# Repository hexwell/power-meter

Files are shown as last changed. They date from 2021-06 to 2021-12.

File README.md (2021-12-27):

# Power Meter

A power meter to read the energy consumption of my house and sound an alert in case it exeeds a threshold.
It consist of two devices:
- A meter that measures the power value and broadcasts it
- An alarm that receives the value and upon need sounds the alarm

Current sensing is done via an external current transformer (CT).

## Meter pictures

TODO

## Firmware

The firmware of both devices can be flashed with the Arduino IDE software, selecting the **Arduino Leonardo** board.

### Libraries

- [RF24](https://github.com/nRF24/RF24)
- [LiquidCrystal_I2C](https://github.com/johnrickman/LiquidCrystal_I2C)

## Early prototype

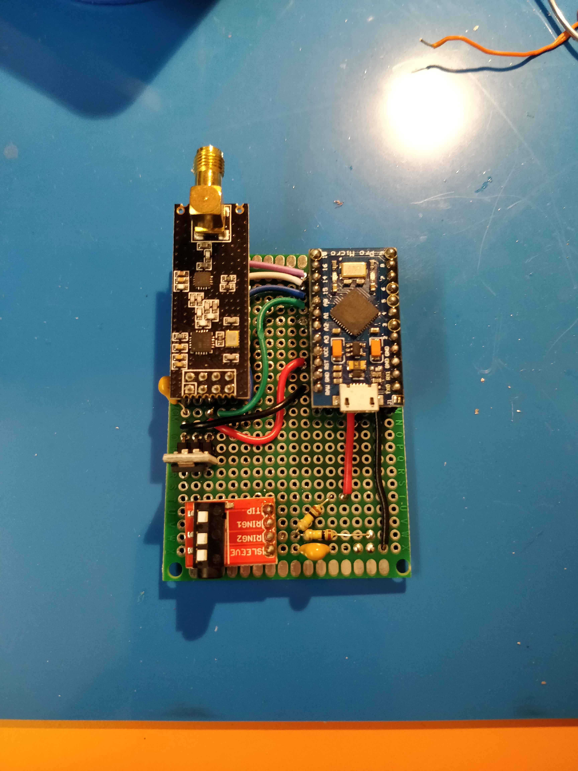
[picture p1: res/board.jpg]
board

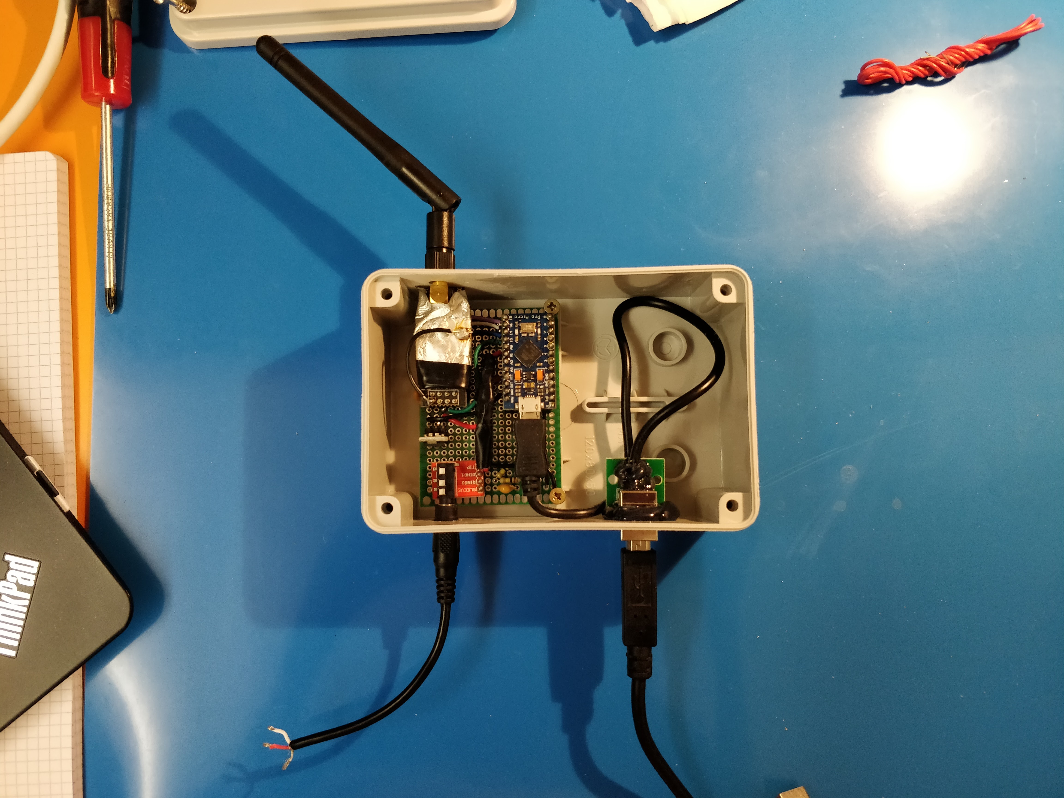
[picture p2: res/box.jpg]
box


## Notes

- A _true_ RMS reading of the sensor is crucial in order to get the real power value. The RMS reading is because of the nature of AC currents. The _true_ RMS is necessary because of the different current waveform of various types of loads (resistive, inductive, capacitive, etc.)
- Power consumption of the final build is .05 A at 5 V
- If the board ever gets **bricked**, [my guide](https://github.com/hexwell/notes-public/blob/master/en/electronics/pro_micro_brick.md) might be of use.
- OpenMeter update rate: 2s
- It might be nice to keep in this readme some pictures from the prototype when I design the PCB and update it.

## Theoretical resolution limits of SCT-013-000V current transformer (CT)

                    // Mains Characteristics
                    rms grid voltage = 230

                    transformer input = 100 A
                   transformer output = 1 V

                                  vcc = 4.683 V
                        adc divisions = 1024

                   volts per division = vcc / adc divisions
                                      = 0.004573
      divisions per transformer_range = transformer output / volts per division
                                      = 218
                    amps per division = transformer input / divisions per transformer_range
                                      = 0.4587
                           resolution = amps per division * rms_grid_voltage
                                      = 105.5010 W

    A lower rating transformer version can be used to get better resolution.
    This circuit can only take (VBUS / 2) input voltage, so the maximum peak current the meter
    can take is "transformer input current" * (VBUS / 2) / "transformer output voltage".
    For electrical systems rated 3.3 kW at 230 V the maximum amperage is 14.34 A,
    but peaks can greatly exceed this value, so at least 10x of this value should be accounted for in the design and transformer choice.
    The 60 A version is pretty much as low as it's possible to go.

## Questioning the whole thing

Since measuring power using just a current transformer is probably not really accurate, another option is reading the power measurement of the energy company's power meter directly, via it's IR port. That would require a lot of work tho, since the protocol needs to be reverse engineered. Irony of sorts, my italian energy company's meter is named OpenMeter.

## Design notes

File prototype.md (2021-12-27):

## Prototype circuit design notes

The circuit of both devices is pretty trivial. For both devices it's just an Arduino Pro Micro with an NRF24L01 transceiver (connected via the standard SPI configuration) and voltage regulation since the Arduino I had laying around was a 5V version and the transceiver is 3.3V. In addition to this, the meter has a voltage divider to DC bias the sensor and the alarm has a speaker directly connected between GND and a pin. Below are some considerations on actually assembling the devices:

- An SCT-013-000V current transformer with integrated burden resistor is used, because I didn't have a precise enough one. The other model (SCT-013-000) tho had integrated TVS diodes for protection instead, that now I need to integrate externally. (See note)
- A voltage divider DC-biases the current transformer/sensor in order to move the current waveform in the safe and measurable range of the Arduino ADC (as in the negative half cycle the voltage across the sensor is negative). The capacitor to ground is for stability of the bias voltage
- A 10 μF capacitor is placed between the power rails of the Arduino, as close as possible to it, for ADC stability as it need a stable supply to make precise measurements
- A shielded cable is used to carry the signal from the the sensor to the Arduino, although it probably is not needed as the frequency is only 50 Hz
- A NRF24L01+PA+LNA transceiver module (with RFAXIS RFX2401C chip) is used. The version with the RFAXIS PA+LNA was chosen for better range and for the SMA connector, allowing for an external (outside of project enclosure) and orientable antenna
- A 3.3 V regulator module with some capacitors on board off of Amazon is used to supply the transceiver. It saves space and does the job fine
- An additional 10 μF stability/noise filtering capacitor is placed between the transceiver power rails, as close as possible to it, just to be sure (not required with the regulator module)
- The tranceiver is wrapped in a layer of isolant followed by a layer of grounded tin foil to reduce interference, as suggested by [Samy Kamkar](https://github.com/SamyK) in [this youtube video](https://youtu.be/1NBNrgTEwq0?t=760) (12:40)
- All boards with power LEDs had them desoldered for power efficiency (namely: Arduino, 3.3 V regulator board)
- For the final project enclosure, I made a USB B to Arduino Micro USB passthrough since the former is more physically robust
- The current transformer/sensor is connected with a 3.3 mm jack breakout board in order to be easily detached from the device using it's original connector.
- **IMPORTANT** TODO: TVS diodes or some sort of protection against voltages outside of 0-5 V should be placed on the sensor output, as a short circuit could cause a spike that destroys the ADC of the Arduino (See explanation above). Alternatively I could use the other current tranformer with integrated protection and add the resistor. It should not be a difficult modification.

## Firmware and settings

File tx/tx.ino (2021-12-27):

#include "RF24.h"

// Mains Characteristics
#define RMS_GRID_VOLTAGE 230 // V
#define GRID_FREQUENCY 50 // Hz

#define TRANSFORMER_INPUT 100 // A
#define TRANSFORMER_OUTPUT 1 // V

#define SENSOR_PIN A0
#define SENSOR_CALIBRATION 510.3 // RMS analogRead(SENSOR_PIN) with no load, use "calibration" sketch to measure this value

#define VCC 4.683 // V
#define ADC_DIVISIONS 1024 // d

// The power supply injects noise in the sensor output and it gets read as power consumption
#define POWER_SUPPLY_NOISE_CORRECTION 150 // W

// Measurement time (2s @ 50 Hz mains)
const unsigned long SAMPLING_RATE = 5 * GRID_FREQUENCY; // Sa/s
const unsigned long SAMPLING_PERIOD = 1000000 / SAMPLING_RATE; // μs
const unsigned long SAMPLES = 2 * SAMPLING_RATE;

const double VOLTS_PER_DIVISION = VCC / ADC_DIVISIONS; // V/d
const double DIVISIONS_PER_TRANSFORMER_RANGE = TRANSFORMER_OUTPUT / VOLTS_PER_DIVISION;
const double AMPS_PER_DIVISION = TRANSFORMER_INPUT / DIVISIONS_PER_TRANSFORMER_RANGE; // A/d

RF24 radio(5, 10); // CE, CSN

typedef uint16_t payload;

void setup() {
  radio.begin();

  radio.setRetries(0, 0);
  radio.setPayloadSize(sizeof(payload));
  radio.disableDynamicPayloads();
  radio.setAutoAck(false);
  radio.setPALevel(RF24_PA_MAX);
  radio.setDataRate(RF24_250KBPS);

  // The address was chosen randomly (to avoid collisions with other devices)
  // avoiding nibbles that mess with the preable detection circuitry of the nRF24L01,
  // as suggested by this article:
  // http://maniacalbits.blogspot.com/2013/04/rf24-addressing-nrf24l01-radios-require.html
  // linked by TMRh20 here:
  // https://github.com/nRF24/RF24/issues/496#issuecomment-671169580

  // The nibbles to avoid are: 0x0, 0x1, 0x2, 0x5, 0xA, 0xF

  radio.stopListening(); // TODO Check if needed
  
  const uint8_t address[] = {0xCD, 0xE6, 0x36, 0xE7, 0xCD};
  radio.openWritingPipe(address);
}

void loop() {
  unsigned long lastReadAt = micros();
  uint16_t remainingSamples = SAMPLES;

  double rms_summation = 0;

  while (remainingSamples)
    if (micros() - lastReadAt >= SAMPLING_PERIOD) {
        lastReadAt += SAMPLING_PERIOD;

        rms_summation += pow(analogRead(SENSOR_PIN) - SENSOR_CALIBRATION, 2);

        remainingSamples--;
    }

  double rms_current = sqrt(rms_summation / SAMPLES);
  payload power = abs(rms_current * AMPS_PER_DIVISION * RMS_GRID_VOLTAGE - POWER_SUPPLY_NOISE_CORRECTION);

  radio.write(&power, sizeof(payload));
}

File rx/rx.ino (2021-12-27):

#include "RF24.h"
#include <LiquidCrystal_I2C.h>

#include "printf.h"

RF24 radio(9, 10); // CE, CSN

typedef uint16_t payload;

LiquidCrystal_I2C lcd(0x27, 20, 4); // set the LCD address to 0x27 for a 16 chars and 2 line display

void setup() {
  Serial.begin(115200);

  radio.begin();

  radio.setPayloadSize(sizeof(payload));
  radio.disableDynamicPayloads();
  radio.setAutoAck(false);
  radio.setPALevel(RF24_PA_MIN);
  radio.setDataRate(RF24_250KBPS);

  const uint8_t address[] = {0xCD, 0xE6, 0x36, 0xE7, 0xCD};
  radio.openReadingPipe(0, address);
  
  radio.startListening(); // TODO Check if needed

  delay(5000);
  printf_begin();
  radio.printDetails();

  lcd.init();
  lcd.backlight();
  lcd.setCursor(0, 0);
  lcd.print("0 W");

  pinMode(4, OUTPUT);
}

bool alarm = false;

void loop() {
  if (radio.available()) {
    payload power;

    radio.read(&power, sizeof(payload));

    Serial.println(power);

    lcd.clear();
    lcd.print(power);
    lcd.print(" W");

    alarm = power >= 3500;
  }

  if (alarm) {
    digitalWrite(4, HIGH);
    delay(1);
    digitalWrite(4, LOW);
    delay(1);
  }
}

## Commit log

2020-06-11 fix power value calculation and theoretical stuff. primitive implementation of alarm. calibration sketch
    [calibration.ino, rx.ino, tx.ino]
2020-06-18 solve pipe issue & other minor radio changes
    [rx.ino, tx.ino]
2020-06-20 update calibration, better organize future modifications
2021-06-15 Add prototype pictures
2021-06-15 Add KiCad PCB files [WIP]
    [power_meter.kicad_pcb, power_meter.sch]
2021-06-16 Progress on schematic, delete backups
    [power_meter.sch]
2021-12-25 separate schematic in multiple sheets; annotate components; power section
    [power_meter.kicad_pcb, power_meter.sch, rf.sch]
2021-12-27 add more decoupling caps and notes
    [power_meter.sch, rf.sch]
2021-12-27 rename mains references to grid, clean up readme
    [power_meter.sch]
2021-12-27 small corrections, backup datasheets
    [power_meter.sch]
